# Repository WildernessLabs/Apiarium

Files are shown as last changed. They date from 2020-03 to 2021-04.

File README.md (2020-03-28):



Open source, open-hardware, modern beehive monitoring powered by Meadow.

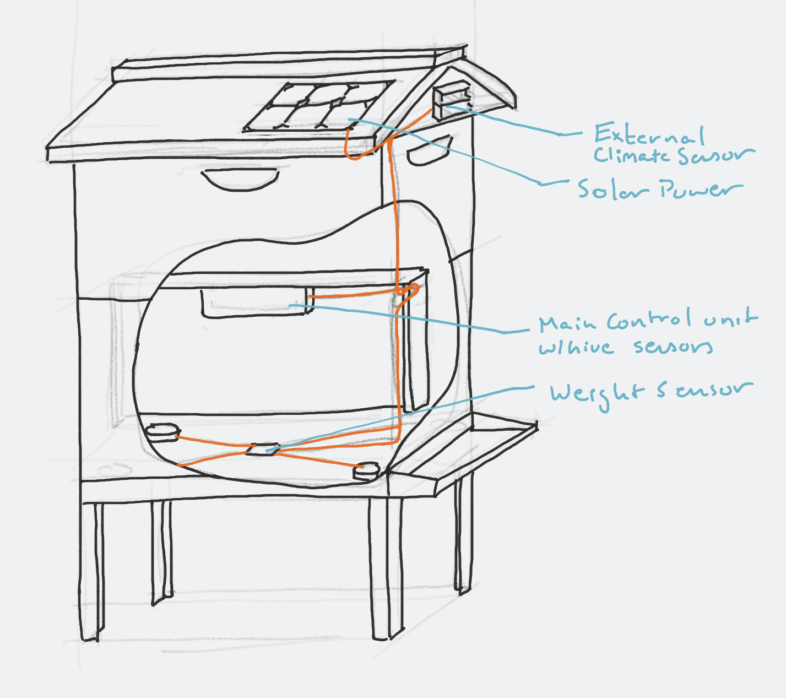
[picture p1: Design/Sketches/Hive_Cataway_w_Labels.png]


It runs on solar power with battery backup, and tracks key bee health and activity metrics, including:

* Internal temp, humidity, and activity (noise)
* Weight of hive

And can also, optionally, track external climate data including temp, humidity, and pressure.

## [Documentation](Documentation)

For a complete instructions on building and installing, check out the [documentation](documentation).

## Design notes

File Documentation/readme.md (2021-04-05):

# Apiarium Documentation

Welcom to the Apiarium docs. Here you'll find guides on building, installing, and using Apiarium, as well as guides on the underlying technology and how to extend it.

## [Assembly & Installation](assembly_and_installation.md)

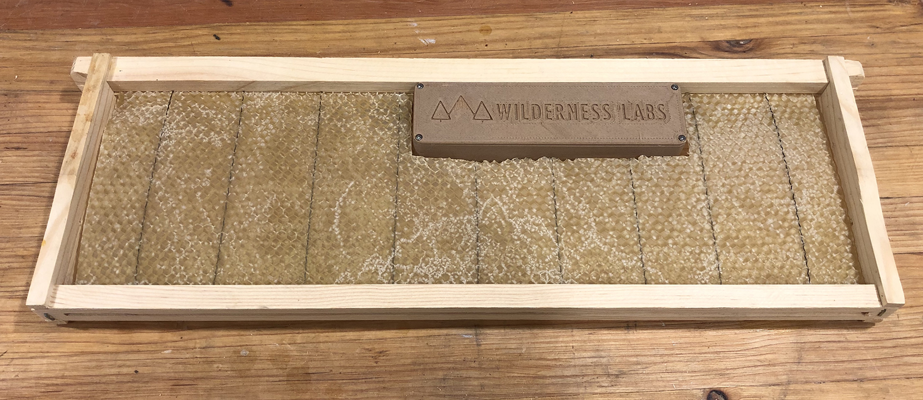
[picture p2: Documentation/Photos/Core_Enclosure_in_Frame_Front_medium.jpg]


Want to get started with Apiarium? Check out the [assembly and installation guide](assembly_and_installation.md).

## Apiarium Application

[guide on understand the application]

## Operation

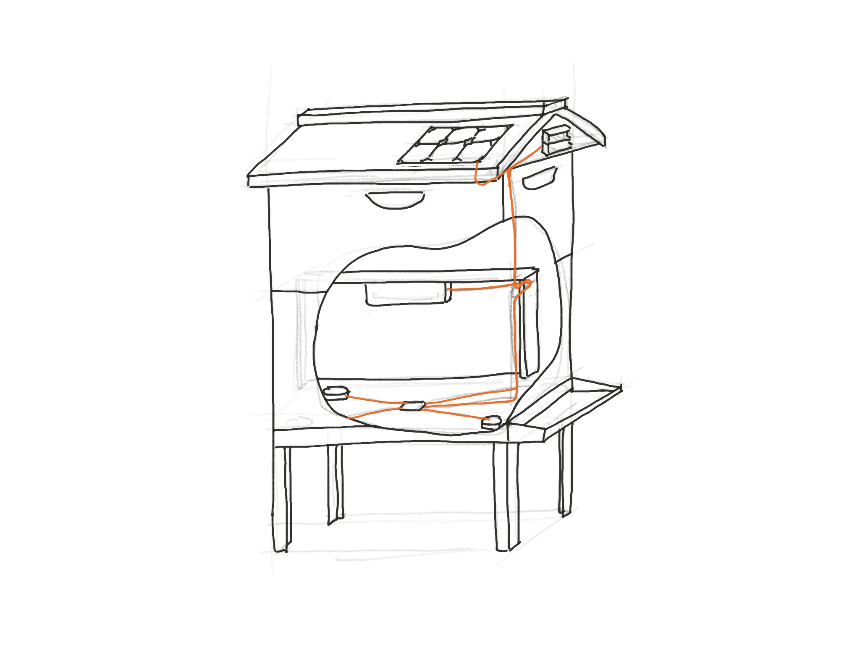
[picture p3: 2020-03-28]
Design/Sketches/Hive_Cutaway.png

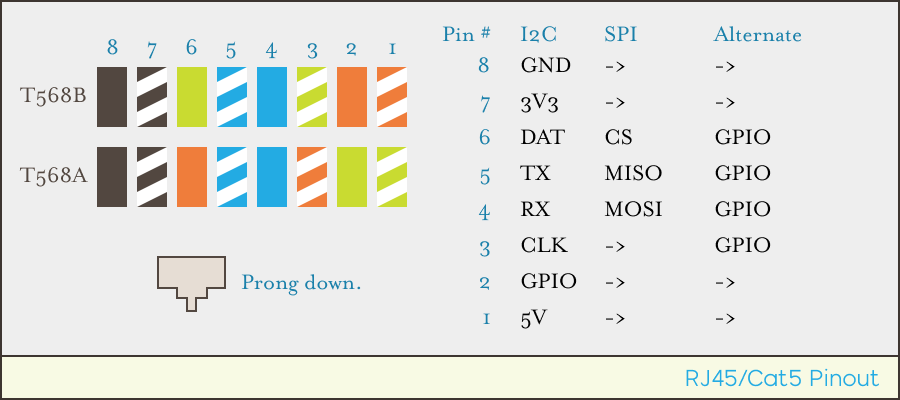
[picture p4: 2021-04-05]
Documentation/Support_Files/RJ45 CAT Pinout.png

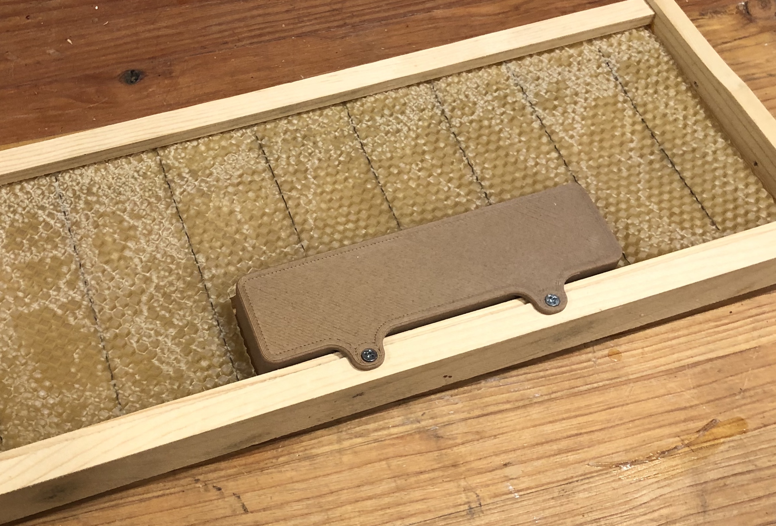
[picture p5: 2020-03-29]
Documentation/Photos/Core_Enclosure_in_Frame_Back.jpg

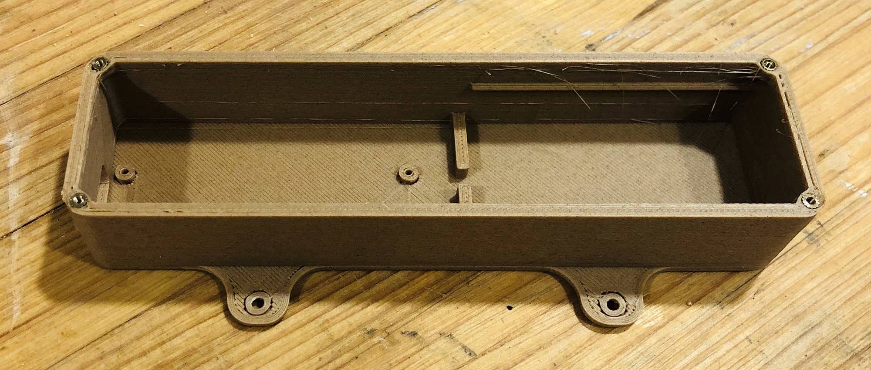
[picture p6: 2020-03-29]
Documentation/Photos/Enclosure_Bottom_medium.jpg

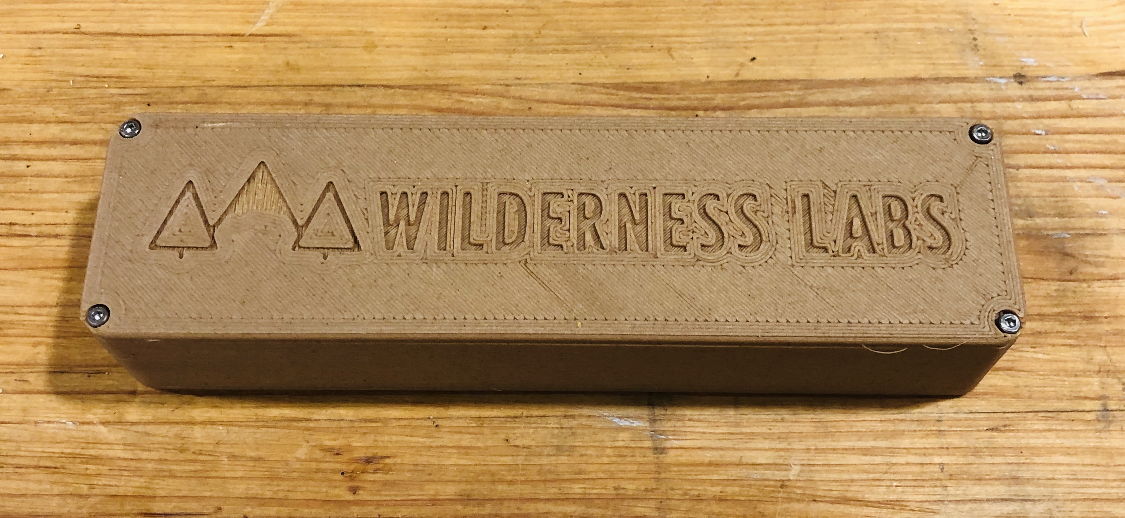
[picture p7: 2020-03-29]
Documentation/Photos/Enclosure.jpg

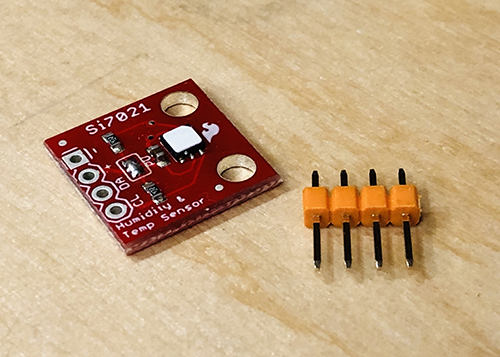
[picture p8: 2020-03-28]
Documentation/Photos/Si7021_small.jpg

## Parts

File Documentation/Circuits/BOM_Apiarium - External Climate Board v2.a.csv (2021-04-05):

ID | Name | Designator | Footprint | Quantity | Manufacturer Part | Manufacturer | Supplier | Supplier Part | Price
1 | 0.1µf | C1,C2 | C0603 | 2 | CC0603KRX7R7BB104 | YAGEO | LCSC | C108079 | 0.0407
2 | 10k | R1,R2 | R0603 | 2 | RC0603FR-0710KL | YAGEO
3 | RJ45 | RJ1,RJ2 | RJ45-TH_5555162-1_FIXED | 2 | 5555162-1 | TE Connectivity | LCSC | C305976 | 1.0468
4 | Optional Solder bridge | U1 | I2C ADDRESS JUMPER | 1 |  |  | Custom
5 | BME280 | U3 | LGA-8_BME280 | 1 | BME280 | Bosch | LCSC | C92489 | 7.656

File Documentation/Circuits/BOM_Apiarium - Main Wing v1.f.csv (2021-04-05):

ID | Name | Designator | Footprint | Quantity | Manufacturer Part | Manufacturer | Supplier | Supplier Part | Price | LCSC Assembly
1 | 0.1µf | C1,C6 | C0603 | 2 | CC0603KRX7R7BB104 | YAGEO | LCSC | C108079 | 0.0407
2 | HDR-F-2.54_1x4 | I2C_HDR | HDR-F-2.54_1X4 | 1 |  |  | LCSC | C225501 | 0.0905
3 | 1725656 | J1 | 1725656 | 1 | 826629-2 | TE Connectivity | LCSC | C86471 | 0.2091
4 | 10K | R1,R2 | R0603 | 2 | RC0603FR-0710KL | YAGEO | LCSC | C98220 | 0.001
5 | SI7021-A20-GM1R | U1 | DFN-6_L3.0-W3.0-P0.95-BL-EP | 1 | SI7021-A20-GM1R | SILICON LABS | LCSC | C132603 | 5.3359 | Yes
6 | Meadow F7 Micro Dev Board | U2 | MEADOWF7MICRO_HEADERS_ONLY | 1 | MEDF7DEV | Wilderness Labs | Mouser | 977-MEADOWF7MICRO
7 | LTC4311ISC6 | U4 | SC-70-6_L2.2-W1.3-P0.65-LS2.2-BL | 1 | LTC4311ISC6#TRPBF

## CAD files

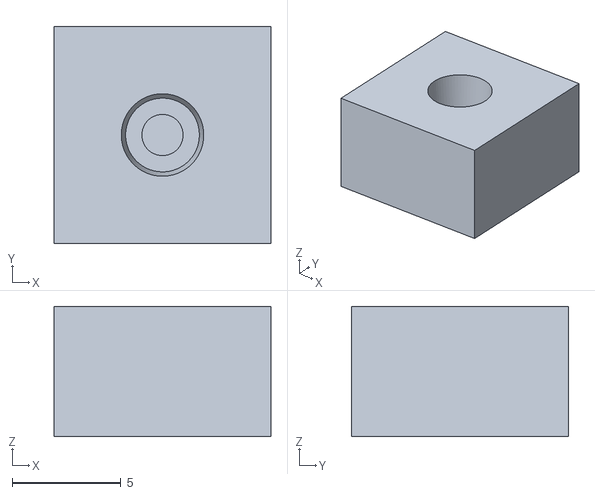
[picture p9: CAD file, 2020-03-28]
Design/Industrial_Design/Printable_Parts/m2_Heat_Insert_Test.stl
10.0 x 10.0 x 6.00

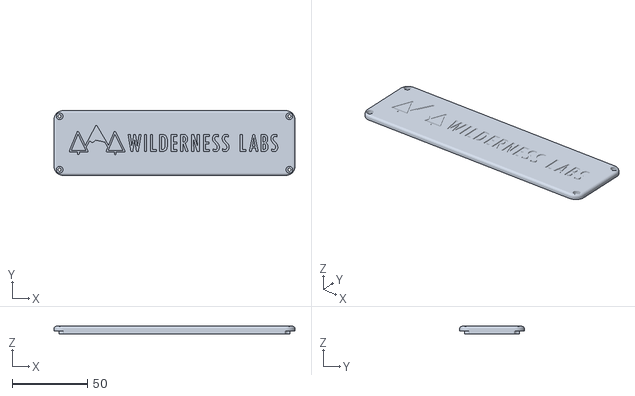
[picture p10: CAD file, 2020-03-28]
Design/Industrial_Design/Printable_Parts/Enclosure_Top.stl
160.0 x 43.0 x 5.00

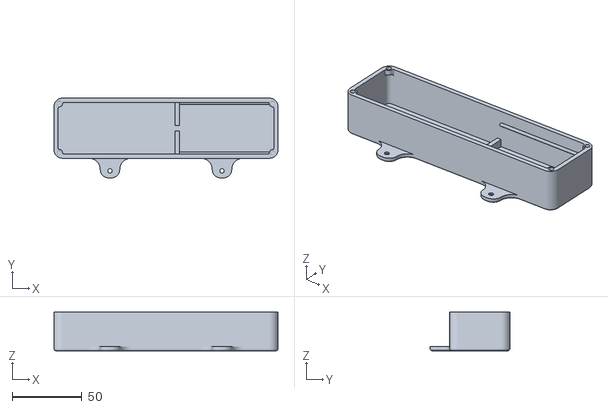
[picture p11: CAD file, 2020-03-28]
Design/Industrial_Design/Printable_Parts/Enclosure_Bottom.stl
160.0 x 57.0 x 27.6

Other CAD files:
Design/Industrial_Design/Enclosure_Model_Source/Apiaria_Meadow_Enclosure.f3d

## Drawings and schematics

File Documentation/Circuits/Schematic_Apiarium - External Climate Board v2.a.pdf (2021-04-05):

# BME 280 RJ45 from Main Wing

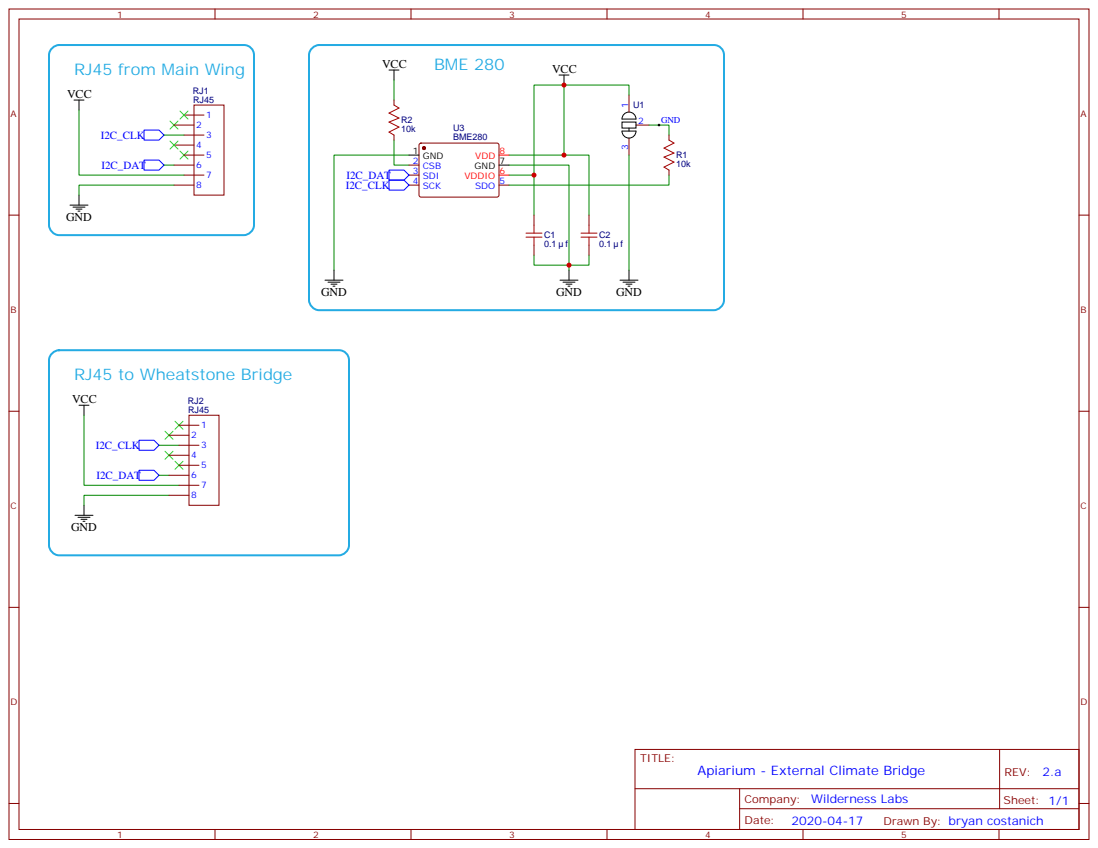
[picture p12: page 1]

Drawn By: bryan costanich

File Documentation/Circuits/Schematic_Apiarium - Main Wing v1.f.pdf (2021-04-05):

Si7021 Temp + Humidity | I2C Pull-ups

# Solah Power

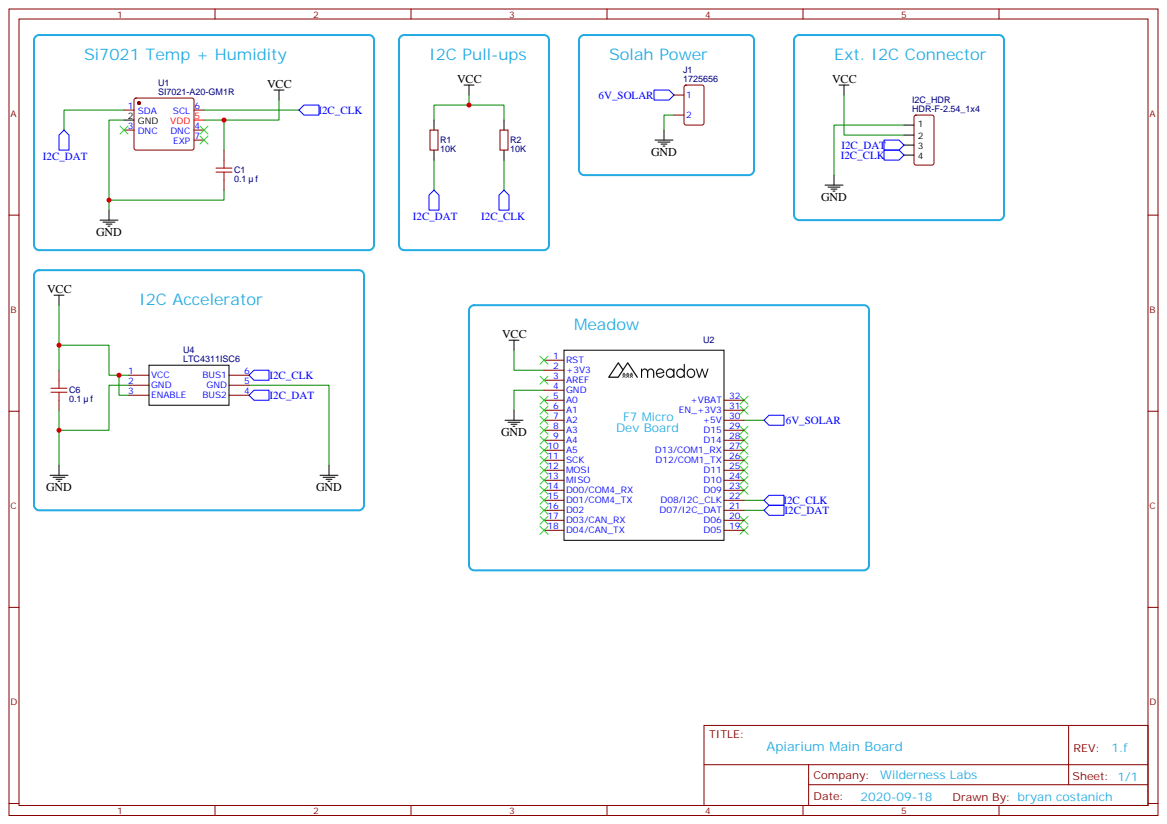
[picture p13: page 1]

Drawn By: bryan costanich

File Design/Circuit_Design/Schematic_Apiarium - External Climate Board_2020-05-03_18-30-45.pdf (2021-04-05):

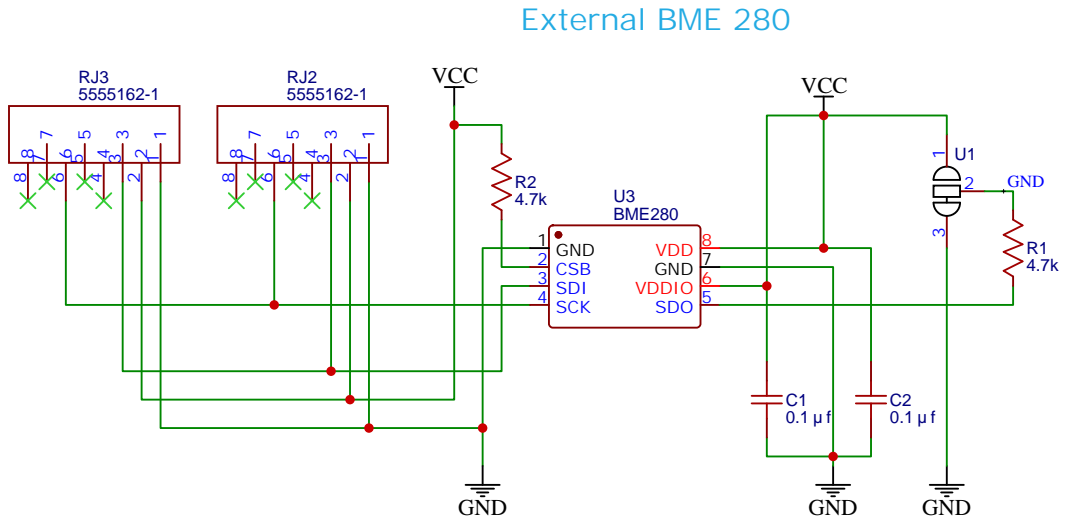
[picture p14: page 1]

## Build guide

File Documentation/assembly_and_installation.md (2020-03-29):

# Assembly & Installation

## Required Components

For the most basic setup, that only tracks internal temp, humidity, and activity, you'll need:

| Component | Description | Image |
|---|---|---|
| **[Langstroth Hive](https://en.wikipedia.org/wiki/Langstroth_hive)** | Modern standard beekeeping hive design. You may be able to fit the enclosure in other hives, but it was designed to fit a standard Langstroth frame. | |
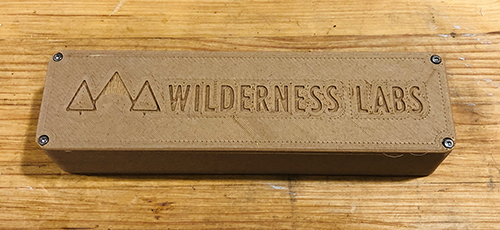
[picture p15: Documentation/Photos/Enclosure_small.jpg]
| **Meadow Apiarium Core Enclosure** | Mounts in a hive frame and contains the core electronics. |  |
| **Core Meadow Controller and Components** | The main components that run the whole thing. | |
| **Solar Panel** | Used to power the system and charge the battery. | |

### Meadow Apiarium Core Enclosure

The Apiarium core enclosure mounts to a Langstroth frame of any height and contains the main Meadow controller, internal sensors, battery, and connectors for external sensors.

It can be printed on nearly any 3D printer, but we recommend printing it in wood PLA, as bees tend to prefer wood over plastic.

The enclosure has two parts, the main enclosure bottom, and a lid:

| Component | Image |
|---|---|
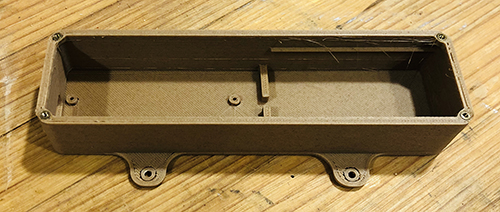
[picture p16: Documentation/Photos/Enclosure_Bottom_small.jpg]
| [Enclosure_Bottom.stl](/Design/Industrial_Design/Printable_Parts/Enclosure_Bottom.stl) |  |
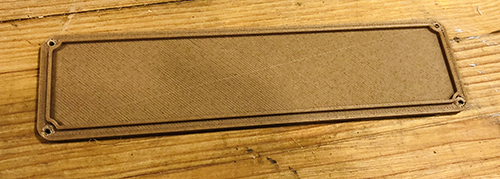
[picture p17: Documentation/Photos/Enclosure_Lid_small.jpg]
| [Enclosure_Top.stl](/Design/Industrial_Design/Printable_Parts/Enclosure_Top.stl) |  |

Additionally, you'll need the following supporting hardware assemble and mount it:

| Component | Description | Image |
|---|---|---|
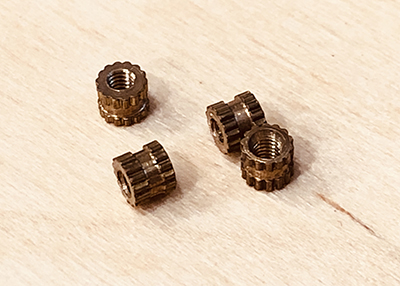
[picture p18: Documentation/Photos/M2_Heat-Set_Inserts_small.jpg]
| (4) M2 heat-set inserts | Provides structural integrity for lid attachment. |  |
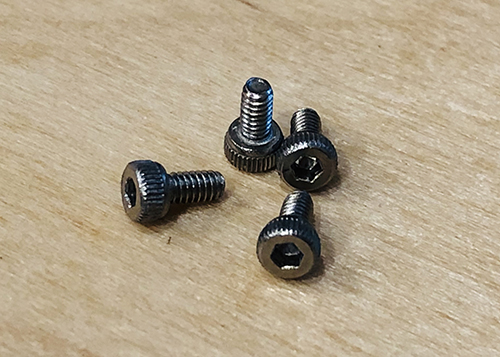
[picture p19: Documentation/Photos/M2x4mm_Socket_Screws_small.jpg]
| (8) M2 x 4mm socket head bolts | Attaches Meadow and Lid to box. |  |
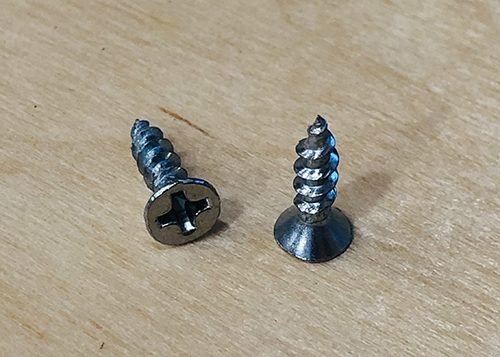
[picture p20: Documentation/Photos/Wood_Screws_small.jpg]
| (2) Wood screws (what size?) | Attaches enclosure to frame. |  |

### Core Meadow Controller and Components

| Component | Description | Image |
|---|---|---|
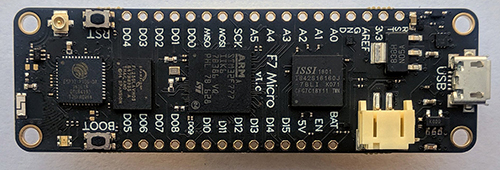
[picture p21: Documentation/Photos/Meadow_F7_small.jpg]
| **[Meadow F7 Dev Board](https://store.wildernesslabs.co/collections/frontpage/products/meadow-f7)** | |  |
| **Meadow Expansion FeatherWing Board** | Provides a permanent platform for attaching components to Meadow. | |
| **Si7021 Temp & Humidity Sensor [SparkFun](https://www.sparkfun.com/products/13763), [Adafruit](https://www.adafruit.com/product/3251)** | I2C temp and humidity sensor. | |
| Breakaway Header | For attaching the Si7021 to the expansion board. | |
| [LiIon Battery](https://www.adafruit.com/product/354) | |
| Microphone (which?) | Measures beehive activity via sound. | |

## Optional Components

### Scale

| Component | Description | Image |
|---|---|---|
| Quality scale | | |
| Wheatstone Bridge | | |

# Installation

[Recommend that you assembly everything and get it validated working before installation]

## Installing in Frame


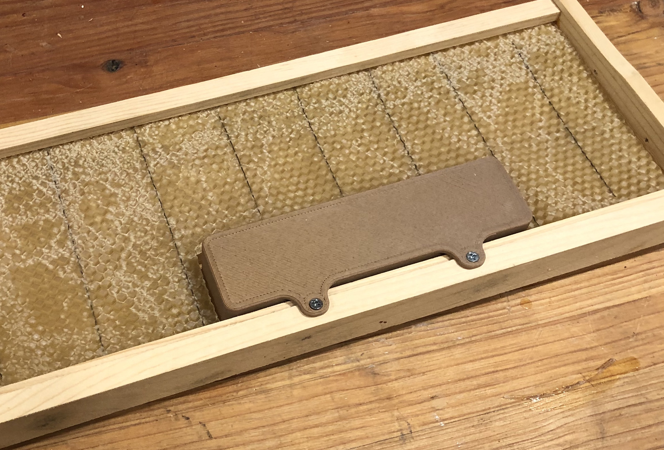
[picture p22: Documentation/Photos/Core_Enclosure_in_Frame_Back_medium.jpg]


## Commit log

2020-03-28 Initial checkin of enclosure model.
    [Apiaria_Meadow_Enclosure.f3d]
2020-03-28 Documentation Content draft
    [Apiaria_Meadow_Enclosure.f3d, Enclosure_Bottom.stl, Enclosure_Top.stl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]
2020-03-28 meadow board.
2020-03-29 Added some images of the enclosure in a hive frame.
2020-03-29 Enclosure phtoos
2020-04-25 Updated design, documentation
    [BOM_Apiarium - External Climate Board_v1.d.csv, BOM_Apiarium_Main_Wing_v1.b.csv]
2021-04-05 Added latest schematics, updated logo
    [BOM_Apiarium - External Climate Board v2.a.csv, BOM_Apiarium - External Climate Board_v1.d.csv, BOM_Apiarium - Main Wing v1.f.csv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]
